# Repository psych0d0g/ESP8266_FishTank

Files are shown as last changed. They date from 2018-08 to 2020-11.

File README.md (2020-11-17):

# ESPtank

IOT ESP8266 Fishtank Controller

ESP8266 Powered Fishtank controller

Tested and developed on LoLin NodeMCU 1.0 ESP8266 Board

PLEASE NOTE: this software is licensed under the MIT license, but used librarys might use other licenses.

### Simplified Schematics

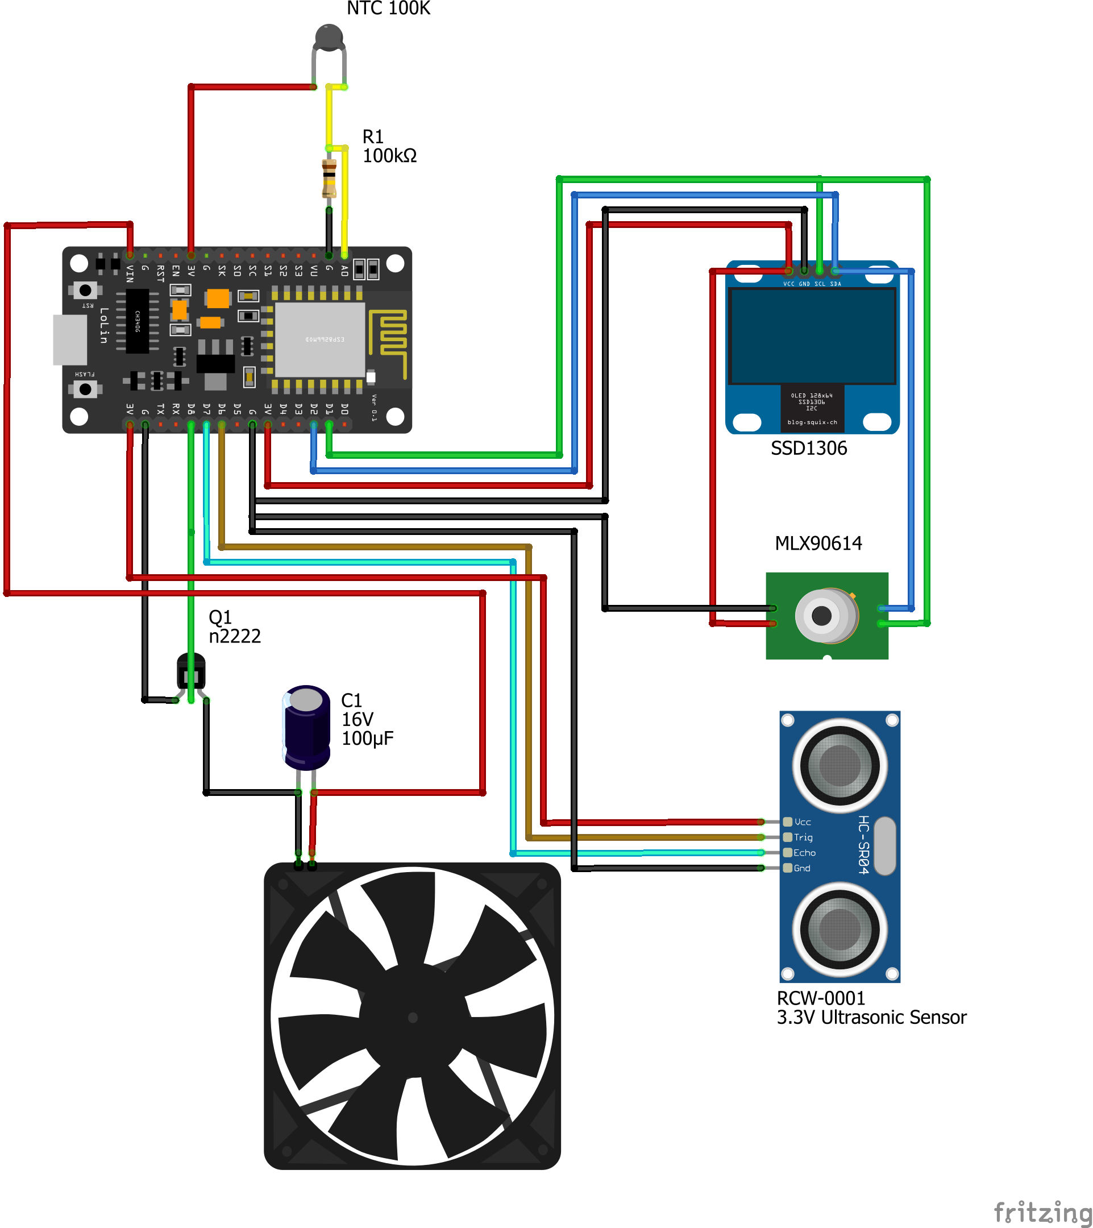
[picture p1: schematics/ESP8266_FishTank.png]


The full fritzing schematic file can be downloaded [here](https://raw.githubusercontent.com/psych0d0g/ESP8266_FishTank/master/schematics/ESP8266_FishTank.fzz)

### Screenshots

Live status Page of the Controller

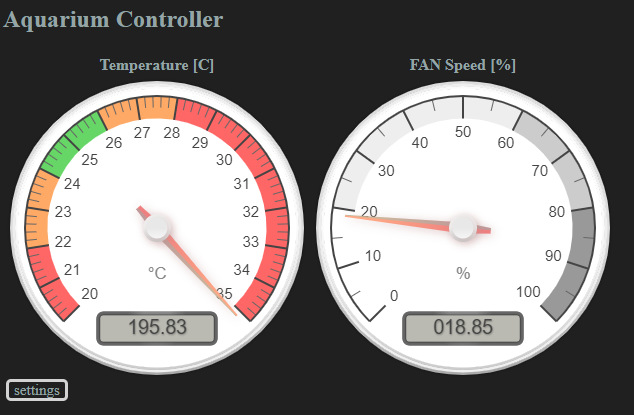
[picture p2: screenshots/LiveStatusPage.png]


Settings page to adjust light and target temps together with the Day/Night mode

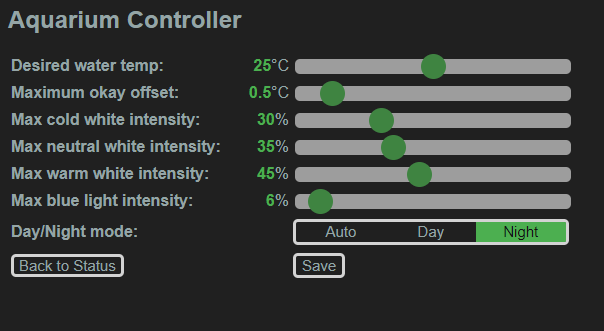
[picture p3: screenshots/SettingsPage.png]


### Current Features

* Measures Temperature from connected NTC 100k thermistor or i2c MLX IR Contactless Temp sensor
* Controls connected FAN using PID PWM
* Displays current Temperature and FAN speed on animated ajax gauges in Browser or on attached i2c Oled screen
* Reads connected Ultrasonic Distance sensor to report on water level (WiP)
* publishes sensor readings to a defined MQTT Server

### Dependencies

Check Platformio.ini for dependencies

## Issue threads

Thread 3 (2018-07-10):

Make Key parameters Configurable on the Web GUI

psych0d0g, 2018-07-10:
Enable the user to set target temperature and maximum difference between measured and desired temperature via webinterface and store the choices in ESP's eeprom (use defaults if nothing has ben stored in eeprom so far)

psych0d0g, 2018-07-10:
Implementation started,
currently the code for reading stored settings is done, storing is a draft, settings page layout done but non functional so far.

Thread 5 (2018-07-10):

Use a i2c IR contactless temperature sensor

psych0d0g, 2018-07-10:
Benefits:

 *   No electronics in the Fishtank
 *   No electric interference for the sensor (the NTC Wires are affected for example by the usually used cathode light in fishtanks)

BernhardQ, 2018-07-11:
Good reason
I use the same sensor chip on an other board.

psych0d0g, 2018-07-23:
sensor ordered, coding will be done once it arrived

psych0d0g, 2018-08-02:
implemented and working

Closed 2018-08-02.

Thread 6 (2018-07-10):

Implement Water level sensing using a Ultrasonic sensor

psych0d0g, 2018-07-10:
Make key parameters configurable (Size of fishtank) to calculate water content of the fishtank in Litres
Display water volume in a nice ajaxified gauge on the webgui

psych0d0g, 2018-07-23:
needs a logic levelshifter since the widely available hc04 Ultrasonic sensors work with 5V whereas the ESP's just use 3.3V

psych0d0g, 2018-08-02:
used a smaller US Sensor, working natively with 3.3 volts,
implemented and working

Closed 2018-08-02.

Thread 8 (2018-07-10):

Build Configuration for Features

psych0d0g, 2018-07-10:
Implement Config to take possibly diffrent hardware components for each task into account.
Example:

Configurable Temperature Sensor, one might use NTC 10k, NTC 100k or an i2c sensor.

Just compile needed bits into the firmware to save precious space

psych0d0g, 2020-11-17:
Implemented and working for temp sensor

Closed 2020-11-17.

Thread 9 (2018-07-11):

Add display Support

psych0d0g, 2018-07-11:
One does not want to fire up a computer or take out a smartphone just to check current temperature readings or other status information of the fishtank, so add a small display (1" OLED via i2c maybe) to display most important values of the controller directly near the fishtank

psych0d0g, 2018-07-23:
i2c oled display on route, implementation soon

psych0d0g, 2018-07-26:
code is ready, hardware diagramm needs updating

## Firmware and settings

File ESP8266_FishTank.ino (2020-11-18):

#include <ESP8266SSDP.h>
#include <DNSServer.h>
#include <LittleFS.h>
#include <Wire.h>
#include <DNSServer.h>
#include "WiFiManager.h"
#include <ArduinoJson.h>

#include "lib/user_config.h"
#include "lib/display.h"
#include "lib/led_control.h"
#include "lib/sensors.h"
#include "lib/webserver.h"
#include "lib/mqtt_handler.h"
#include "lib/time_handler.h"

/**
 * setup
 *
 * Arduino setup function
 */
void setup()
{
  Serial.begin(115200);
  WiFi.hostname( host );
  WiFiManager wifiManager;

  wifiManager.setBreakAfterConfig(true);
  if (!wifiManager.autoConnect("ESP_FishTank")) {
    Serial.println("failed to connect, we will fire up config mode");
    delay(3000);
    wifiManager.startConfigPortal("ESP_FishTank");
    delay(5000);
  }
  Wire.begin();
  Wire.setClock(100000L);
  setupNTP();
  setupPWM();
  setupSensors();
  readConfig();
  displaySetup();
  webserverSetup();
  timerSetup();
  //setupMqtt();
}

/**
 * loop
 *
 * Arduino main loop
 */
void loop()
{
  loopNTP();
  handleLedState();
  handleTempLoop();
  handleWaterLevel();
  printOnScreen(fan_pwm,tempInt);
  //handleMQTT();
  server.handleClient();
}

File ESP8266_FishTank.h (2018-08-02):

#ifndef header_h
#define header_h
//#include "system.h"

// pin Definitions
#define NTC_PIN A0
#define FAN_PIN D8
#define TRIG_PIN D6
#define ECHO_PIN D7

#define OLED_RESET D0

// Wifi Setup
String host = "Fishtank";
const char* mqtt_server = "10.10.10.10";

struct Config {
  double desired_temp = 25;
  double temp_offset = 0.5;
};

int INTERVAL = 5000;   // time between reads

int avgLoop = 5;    //temp measurement loops

//PID parameters.
double kp=20;   //proportional parameter
double ki=5;   //integral parameter
double kd=1;   //derivative parameter

//Minimum and Maximum PWM command, according fan specs and noise level required
double commandMin = 0;
double commandMax = 250;

boolean first = true;
double temp, tempInt, avgInt, tempDiff, fan_pwm;

long duration, distance, lastReadTemp, lastReadLevel;
#endif

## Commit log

2018-07-08 Initial schematics
    [ESPtank.fzz]
2018-07-08 More Clean scheamtics
    [ESPtank.fzz]
2018-07-08 Cleaned schematic render
2018-07-10 Proper README and some Structural repository Changes
    [ESPtank.fzz]
2018-07-10 fix include of fishtank header file
    [ESP8266_FishTank.ino]
2018-07-10 Run Wifi Config if connection fails after 3 seconds
    [ESP8266_FishTank.ino]
2018-07-10 Started implementing dynamic settings
    currently non functional
    still using hardcoded defaults
2018-07-11 fix loading of current settings
    [ESP8266_FishTank.h]
2018-07-11 creation of a nested json object
    fishtank.json returns settings and readings from attached sensors in a single nested json structure
2018-07-26 Initial OLED Support
    Display temp and fan speed on a chep oled display
2018-07-27 Fix copy paste error
    [ESP8266_FishTank.ino]
2018-08-04 Updated Schematics to reflect current possibilities
2018-08-04 fix printing layout for console
2020-11-14 update dependencies and fix deprecations
    [ESP8266_FishTank.ino]
2020-11-14 Fixes, restructuring and switching from adafruit display lib to u8g2
    [ESP8266_FishTank.ino]
2020-11-14 add KiCad schematic and PCB Layout files
    [AQUARIUMCONTROLLER.kicad_pcb, AQUARIUMCONTROLLER.kicad_sch]
2020-11-15 add manual night / daytime override and fix Fan speed fillbar on display
2020-11-16 current state
2020-11-19 add a light switch mode to switch between fading and instant changes of Brightness
